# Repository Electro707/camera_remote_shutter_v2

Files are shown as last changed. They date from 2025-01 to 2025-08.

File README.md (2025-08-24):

# P1010 - Camera Remote Shutter Project V2
#### Rev 2

This is an open-source camera remote shutter.

This was the second revision of the [original project](https://github.com/Electro707/camera_remote_shutter), but is now treated as a seperate project due to scope creep.

Currently working on Rev 2, which is smaller and fixed some issues with V1

# Directory Structure
- `CAD`: FreeCAD enclosure and models
    - C1013: Bottom half of enclosure
    - C1014: Top half of enclosure
- `Firmware`: Firmware. Currently contains only test firmware
- `PCB`: KiCAD PCB Files
    - E1011: PCB
- `Release`: Locked in "released" files, such as Schematics, Gerbers, etc
- `SimTest`: A simulation I did in KiCAD for the trans-impedance amplifier

## Erratas
All hardware erratas and potential work-arounds are documented in [ERRATA.md](ERRATA.md)

## Firmware
WIP, currently only test firmware exists

### Setup
This project uses [stm32-cmake](https://github.com/ObKo/stm32-cmake) in the build process, so you must set it up and change the `CMAKE_TOOLCHAIN_FILE` variable in each firmware's CMAKE file. You must also download [STM32G0's MCU Package](https://github.com/STMicroelectronics/STM32CubeG0) and set the `STM32_CUBE_G0_PATH` variable to the download location.
Optionally if you have stm32cubeide installed, setup `STM32_TOOLCHAIN_PATH` in the CMAKE file, or remove it

### Compiling
To build any of the test or main applications, go into that directory and run the following:
```bash
mkdir -p build
cd build
cmake ../
make
```

### Programming
To upload the program, run the following stlink command
```bash
st-flash write <file_to_flash>.bin 0x08000000
```

Where the <file_to_flash> is the bin file inside of the build folder. `0x08000000` is the starting flash address for the STM32G0 family.

## KiCAD 3D Models
The 3D models for some components in the directory `PCB/3d_model/` are not included due to licensing reasons. You can grab the step files yourself and put it in that directory from the manufacturer. The models are
- CUI_DEVICES_SJ-2509N.step
- 615006138421_Download_STP_615006138421_rev1.stp
- c-1-1478035-0-b-3d.stp
- pec12r-4025f-n0024.stp

# License
This project is licensed under GPLv3. See [LICENSE.md](LICENSE.md) for details.

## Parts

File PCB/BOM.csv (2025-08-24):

Reference | Value | Footprint | Qty | DNP
BT2 | Battery | Connector_JST:JST_PH_B2B-PH-K_1x02_P2.00mm_Vertical | 1
C1 | 10pF | Capacitor_SMD:C_0805_2012Metric | 1
C2,C6,C14,C18 | 1pF | Capacitor_SMD:C_0805_2012Metric | 4
C3,C5,C11,C12,C17,C20 | 0.1uF | Capacitor_SMD:C_0805_2012Metric | 6
C4,C13 | 10uF | Capacitor_SMD:C_0805_2012Metric | 2
C7 | 1uF | Capacitor_SMD:C_0805_2012Metric | 1
C8 | 4.7uF | Capacitor_SMD:C_0805_2012Metric | 1
C9,C10,C19 | 10nF | Capacitor_SMD:C_0805_2012Metric | 3
D1 | D_Photo | LED_THT:LED_D5.0mm | 1
D4 | ESD5Zxx | Diode_SMD:D_SOD-523 | 1
F2 | Polyfuse | Fuse:Fuse_1210_3225Metric_Pad1.42x2.65mm_HandSolder | 1
FB1 | FerriteBead | Fuse:Fuse_0805_2012Metric | 1
H1,H2,H3,H4 | MountingHole_Pad | MountingHole:MountingHole_3.2mm_M3_DIN965_Pad | 4
J1 | External Trig | ProjectLibrary:MJ1-2503A | 1
J2 | Conn_01x02_Socket | Connector_PinHeader_2.54mm:PinHeader_1x02_P2.54mm_Vertical | 1
J4 | RJ12 | Connector_RJ:RJ25_Wayconn_MJEA-660X1_Horizontal | 1
J6 | Camera TRS | ProjectLibrary:MJ1-2503A | 1
J8 | USB_C_Receptacle_USB2.0_14P | Connector_USB:USB_C_Receptacle_GCT_USB4085 | 1
MK1 | Microphone | Sensor_Audio:POM-2244P-C3310-2-R | 1
Q3,Q4 | MMBF170 | Package_TO_SOT_SMD:SOT-23 | 2
R1,R21,R22 | 0 | Resistor_SMD:R_0805_2012Metric | 3
R2,R8 | 100k | Resistor_SMD:R_0805_2012Metric | 2
R5,R25,R27,R29,R30,R34,R36,R38,R39,R42,R45,R49,R50 | 1k | Resistor_SMD:R_0805_2012Metric | 13
R6,R7,R9,R14,R19,R28,R31,R32,R33,R35,R37,R41,R48 | 10k | Resistor_SMD:R_0805_2012Metric | 13
R10 | 200k | Resistor_SMD:R_0805_2012Metric | 1
R13 | 2.2k | Resistor_SMD:R_0805_2012Metric | 1
R16,R24,R53 | 0 | Resistor_SMD:R_0805_2012Metric | 3 | DNP
R17,R18 | 5.1k | Resistor_SMD:R_0805_2012Metric | 2
R23 | x | Resistor_SMD:R_0805_2012Metric | 1 | DNP
R26 | 1.3k | Resistor_SMD:R_0805_2012Metric | 1
R40 | 100 | Resistor_SMD:R_0805_2012Metric | 1
R43 | 10k | Resistor_SMD:R_0805_2012Metric | 1 | DNP
R51 | 500k | Resistor_SMD:R_0805_2012Metric | 1
R52 | 1M | Resistor_SMD:R_0805_2012Metric | 1
SW1,SW2,SW3 | SW_Push | Button_Switch_THT:SW_PUSH_6mm,Button_Switch_THT:SW_Tactile_SPST_Angled_PTS645Vx58-2LFS | 3
SW5 | RotaryEncoder_Switch | Rotary_Encoder:RotaryEncoder_Bourns_Vertical_PEC12R-3x17F-Sxxxx | 1
TP1,TP2,TP3,TP4 | TestPoint | TestPoint:TestPoint_Keystone_5005-5009_Compact,TestPoint:TestPoint_Pad_D1.5mm | 4
U1 | STM32G071K8Tx | Package_QFP:LQFP-32_7x7mm_P0.8mm | 1
U2,U8 | LTV-356T | Package_SO:SO-4_4.4x3.6mm_P2.54mm | 2
U3 | ER-TFTM1.28-1 | ProjectLibrary:1.28IN LCD | 1
U4 | BQ24072RGT | Package_DFN_QFN:VQFN-16-1EP_3x3mm_P0.5mm_EP1.6x1.6mm | 1
U5 | OPA2607 | Package_SO:SOIC-8_3.9x4.9mm_P1.27mm | 1
U6 | TS5A3357 | Package_SO:VSSOP-8_2.3x2mm_P0.5mm | 1
U9 | TLV75733PDBV | Package_TO_SOT_SMD:SOT-23-5 | 1

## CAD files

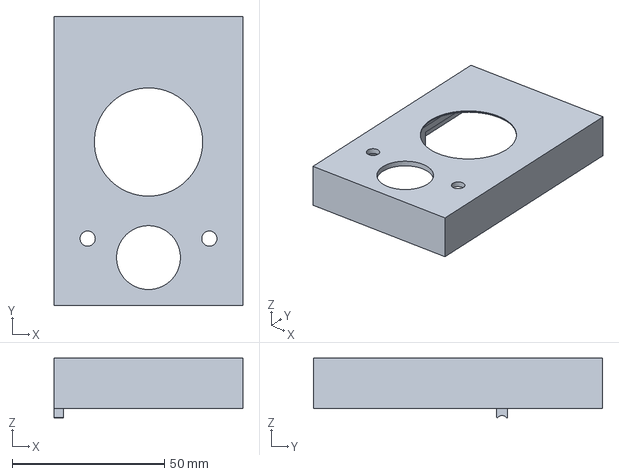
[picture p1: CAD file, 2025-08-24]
CAD/Enclosure.FCStd
62.0 x 95.0 x 19.7 mm

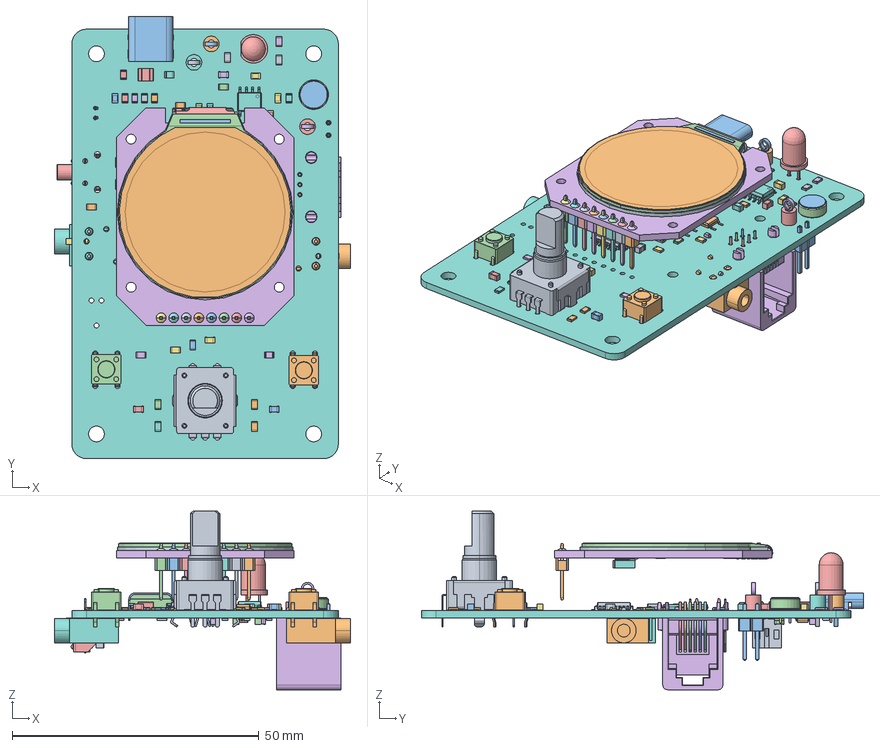
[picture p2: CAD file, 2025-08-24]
CAD/PCB_Rev2.FCStd
60.0 x 89.6 x 36.2 mm
SOT-23
R_0805_2012Metric
R_0805_2012Metric001
SW_PUSH_6mm
R_0805_2012Metric002
D_SOD-523
R_0805_2012Metric003
C_0805_2012Metric
LQFP-32_7x7mm_P0.8mm
R_0805_2012Metric004
C_0805_2012Metric001
R_0805_2012Metric005
LED_D5.0mm
R_0805_2012Metric006
C_0805_2012Metric002
R_0805_2012Metric007
ÃÂºÃÂ¿
ÃÂºÃÂ¿001
ÃÂºÃÂ¿002
ÃÂºÃÂ¿003
ÃÂºÃÂ¿004
ÃÂµÃ¨ÂÂ·ÃÂ°
Pin Header 8P
Pin Header 8P001
Pin Header 8P002
Pin Header 8P003
Pin Header 8P004
Pin Header 8P005
Pin Header 8P006
Pin Header 8P007
Pin Header 8P008
Pin Header 8P009
Pin Header 8P010
Pin Header 8P011
Pin Header 8P012
Pin Header 8P013
Pin Header 8P014
Pin Header 8P015
FPC-12
FPC-013
FPC-014
FPC-015
FPC-016
FPC-017
FPC-018
FPC-019
FPC-020
FPC-021
FPC-022
FPC-023
FPC-024
FPC-025
FPC-026
FPC-027
FPC-028
R_0805_2012Metric008
R_0805_2012Metric009
R_0805_2012Metric010
R_0805_2012Metric011
R_0805_2012Metric012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

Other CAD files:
CAD/Assembly.FCStd

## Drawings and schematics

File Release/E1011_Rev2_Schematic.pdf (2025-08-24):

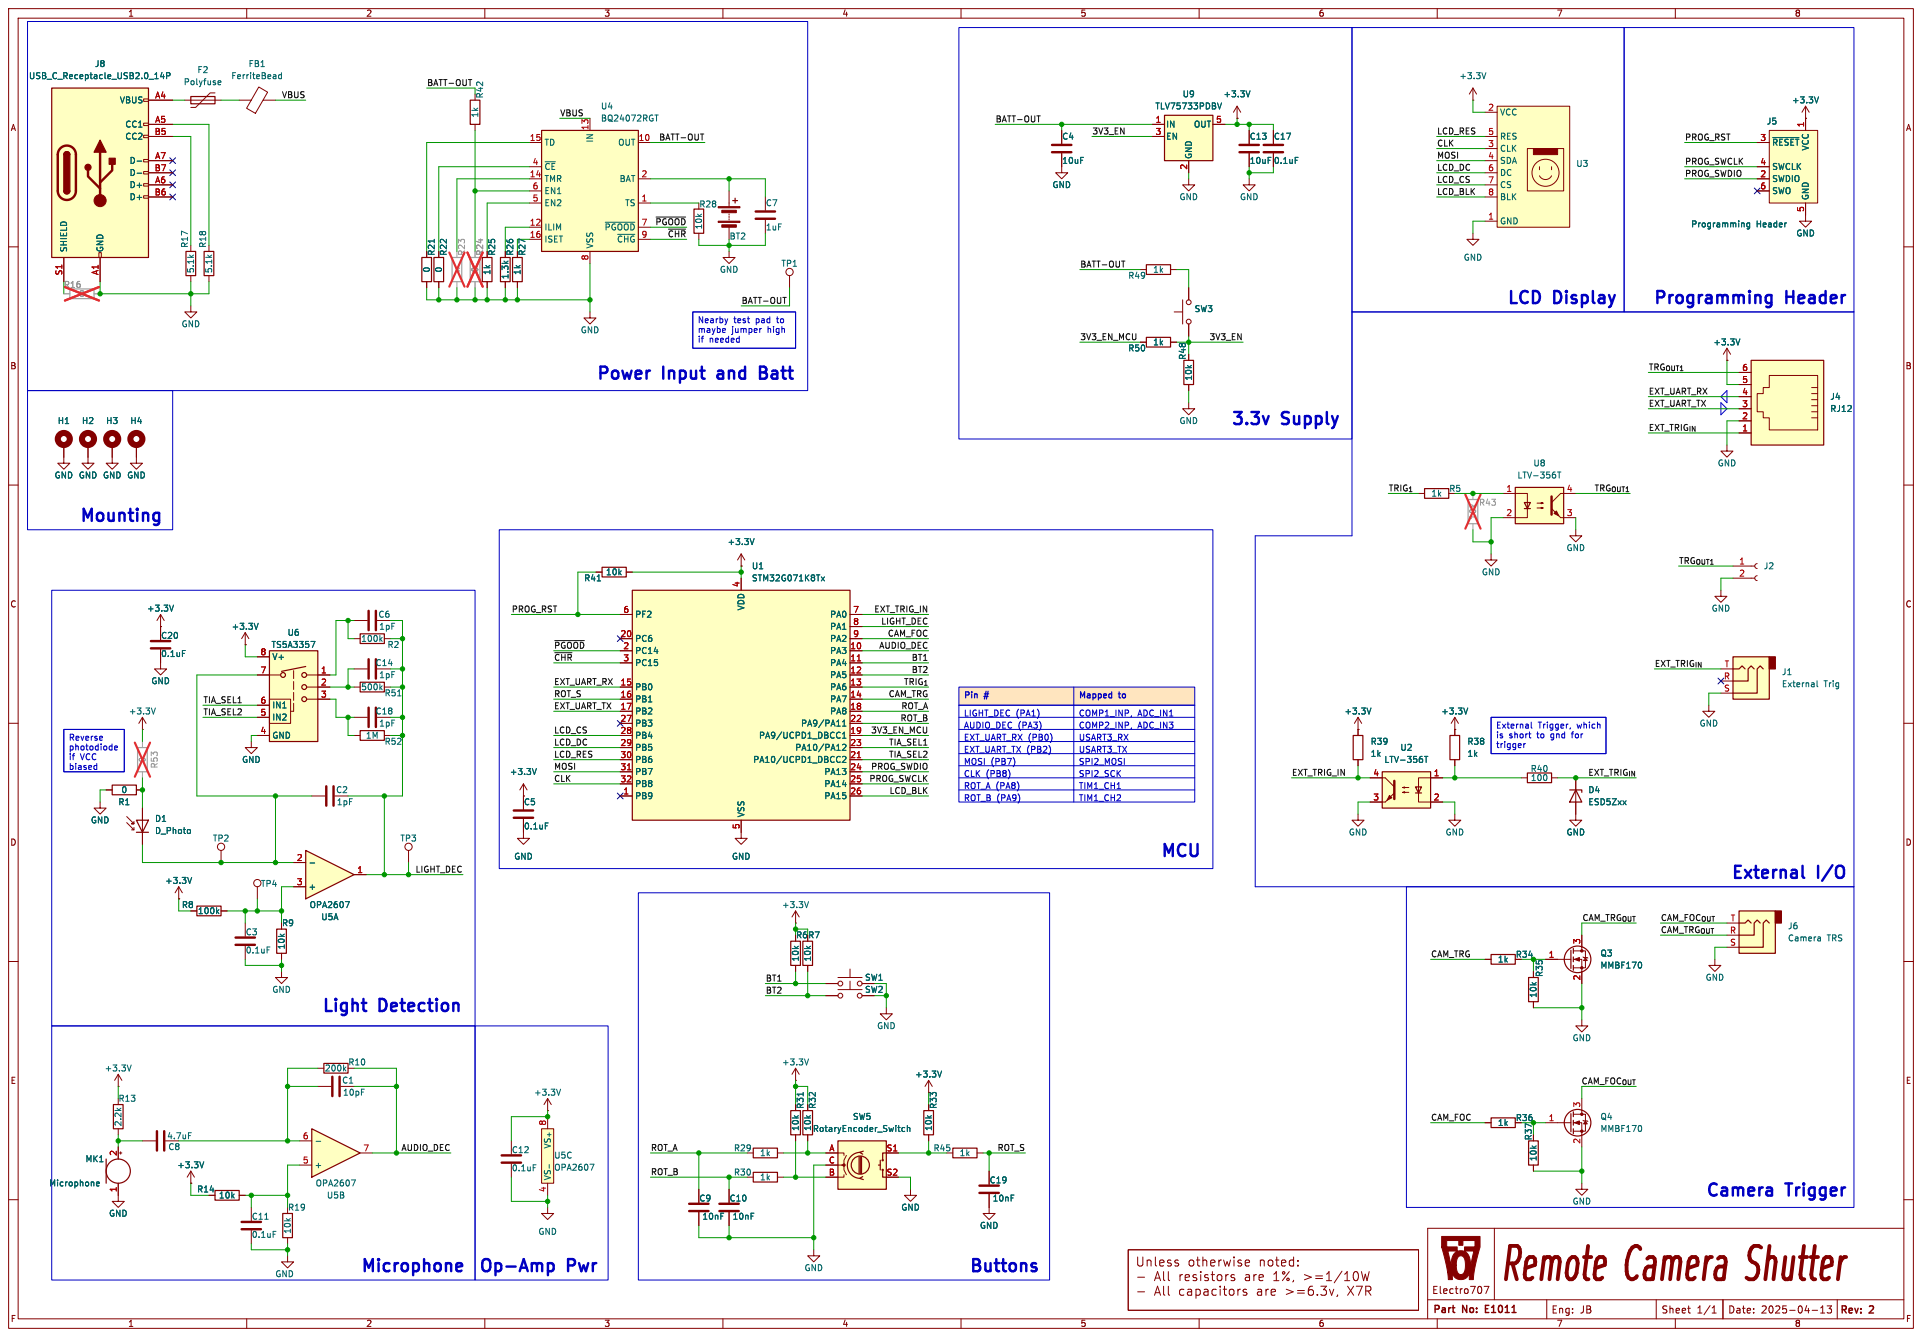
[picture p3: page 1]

8 OUT 10 BAT 2 TS 1 ~{PGOOD}7 ~{CHG}9 U4BQ24072RGT
VBUS

Nearby test pad to maybe jumper high

Power Input and Batt

External Trigger, which
is short to gnd for
trigger

Microphone Op-Amp Pwr

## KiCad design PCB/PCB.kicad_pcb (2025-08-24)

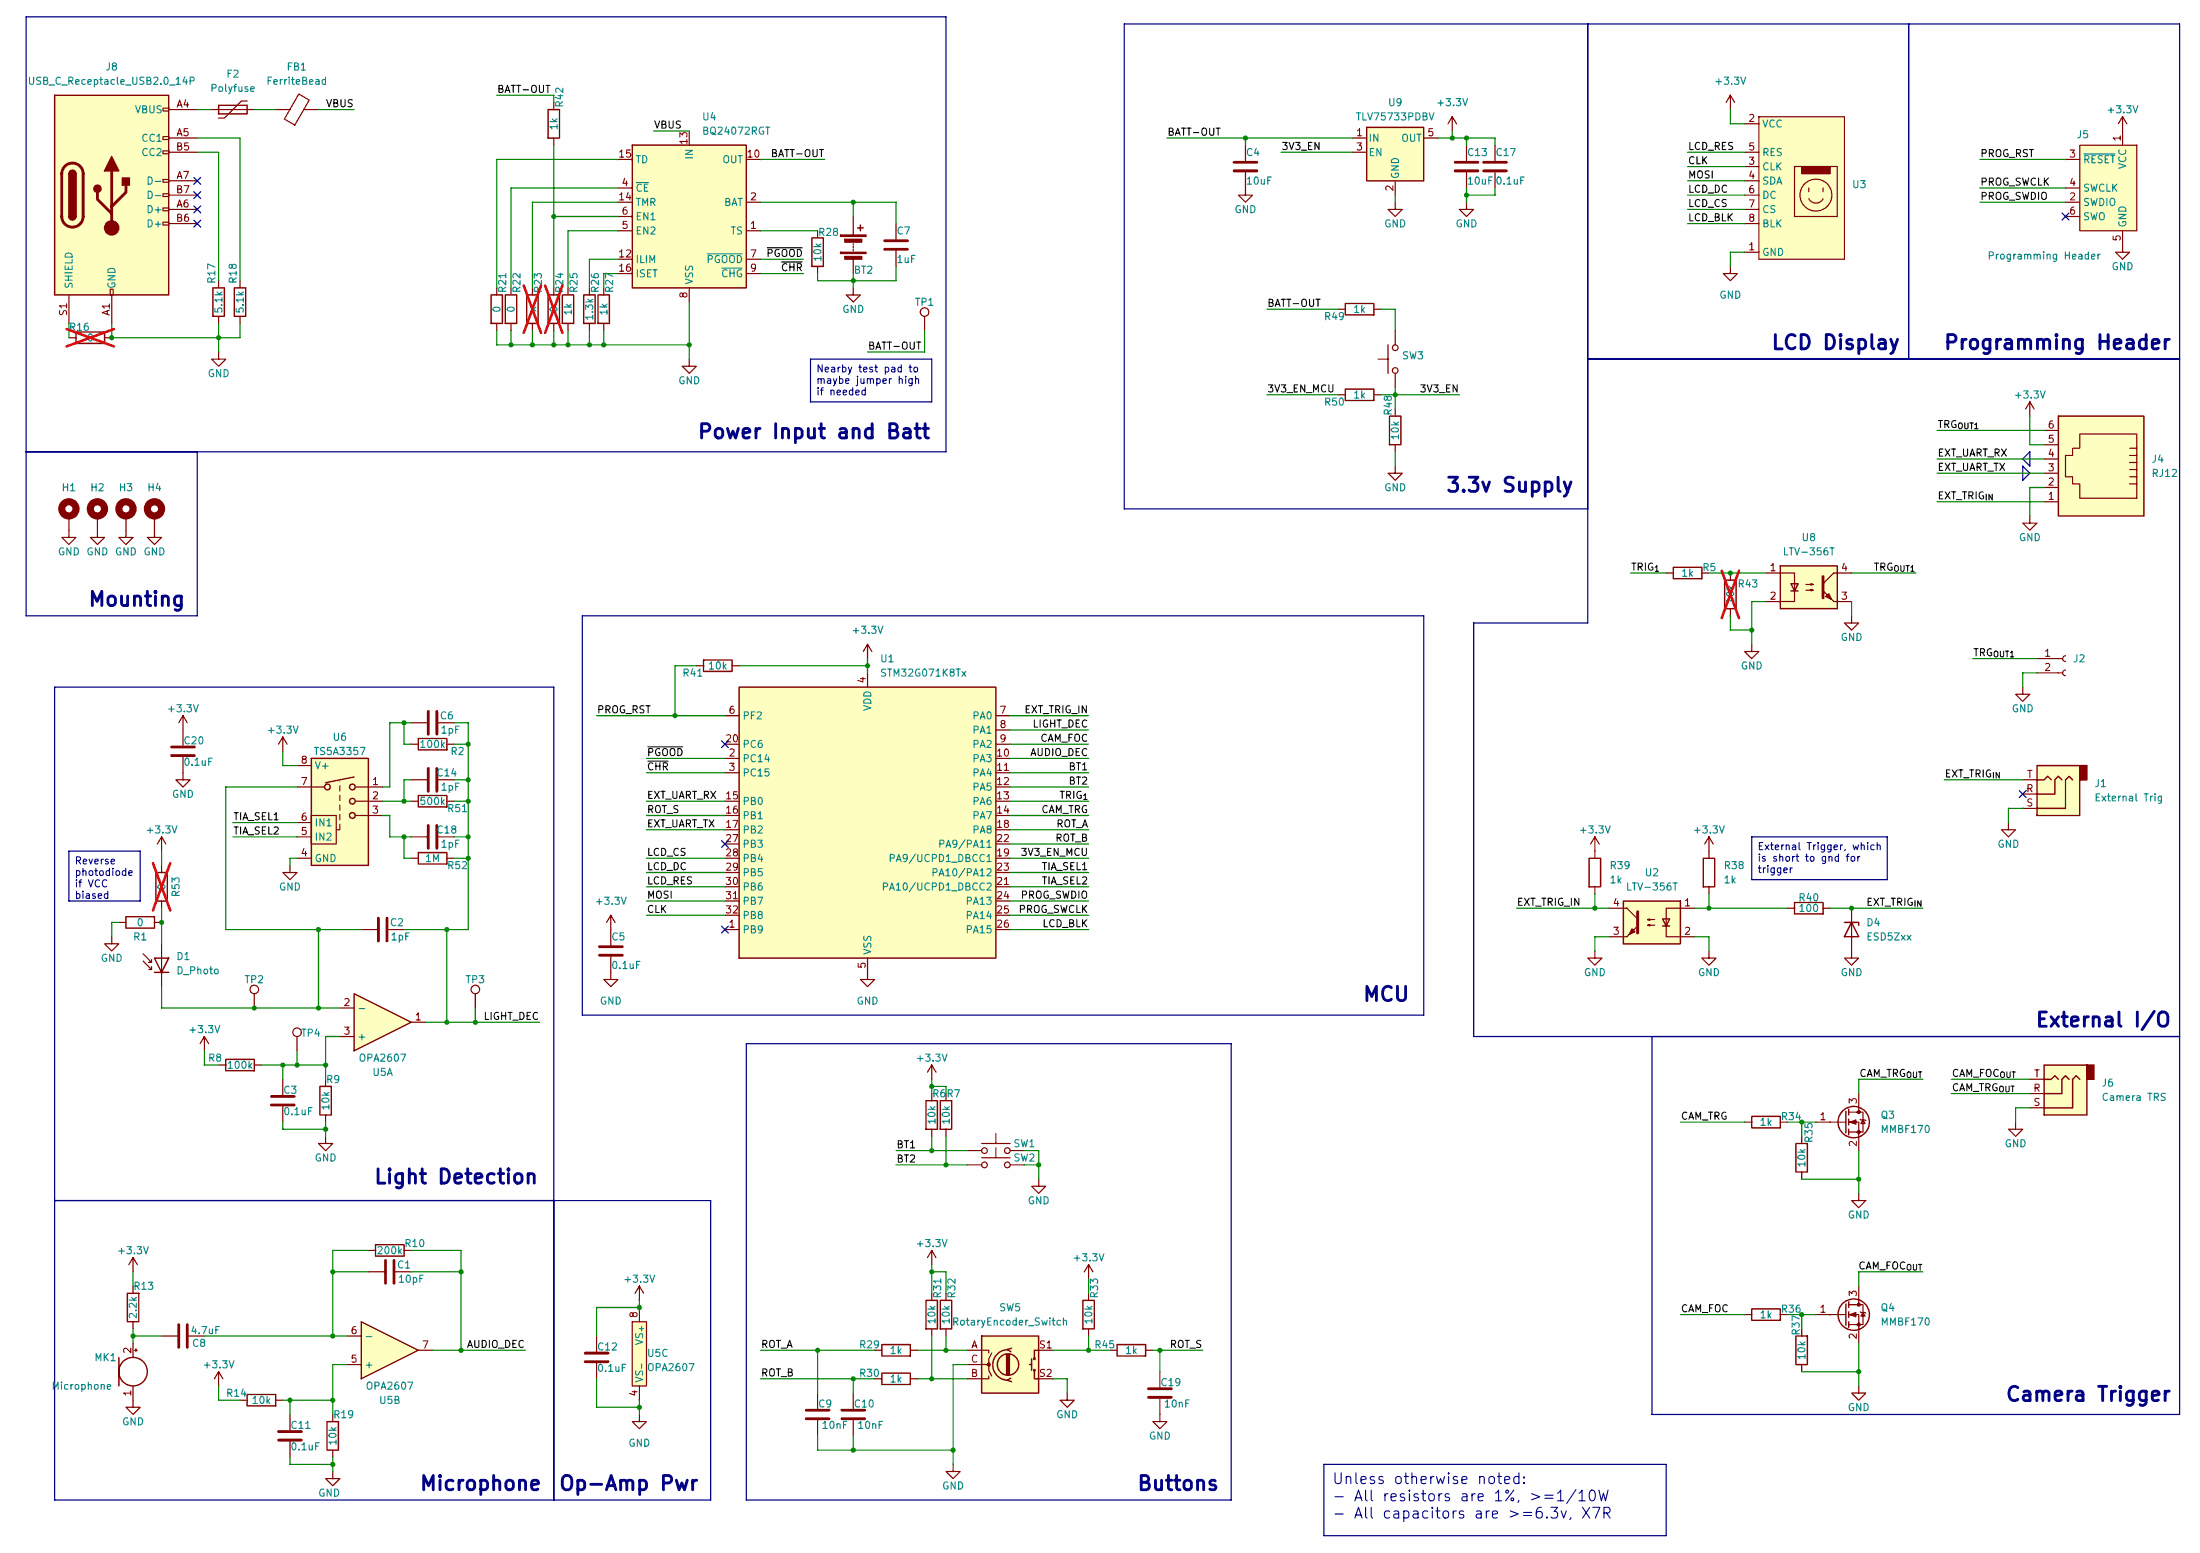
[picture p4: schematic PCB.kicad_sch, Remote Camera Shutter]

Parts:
BT2: Battery; JST_PH_B2B-PH-K_1x02_P2.00mm_Vertical
C1: 10pF; C_0805_2012Metric
C2, C6, C14, C18: 1pF; C_0805_2012Metric
C3, C5, C11, C12, C17, C20: 0.1uF; C_0805_2012Metric
C4, C13: 10uF; C_0805_2012Metric
C7: 1uF; C_0805_2012Metric
C8: 4.7uF; C_0805_2012Metric
C9, C10, C19: 10nF; C_0805_2012Metric
D1: D_Photo; LED_D5.0mm
D4: ESD5Zxx; D_SOD-523
F2: Polyfuse; Fuse_1210_3225Metric_Pad1.42x2.65mm_HandSolder
FB1: FerriteBead; Fuse_0805_2012Metric
H1, H2, H3, H4: MountingHole_Pad; MountingHole_3.2mm_M3_DIN965_Pad
J1: External Trig; MJ1-2503A
J2: Conn_01x02_Socket; PinHeader_1x02_P2.54mm_Vertical
J4: RJ12; RJ25_Wayconn_MJEA-660X1_Horizontal
J5: Programming Header; Tag-Connect_TC2030-IDC-NL_2x03_P1.27mm_Vertical
J6: Camera TRS; MJ1-2503A
J8: USB_C_Receptacle_USB2.0_14P; USB_C_Receptacle_GCT_USB4085
MK1: Microphone; POM-2244P-C3310-2-R
Q3, Q4: MMBF170; SOT-23
R1, R21, R22: 0; R_0805_2012Metric
R2, R8: 100k; R_0805_2012Metric
R5, R25, R27, R29, R30, R34, R36, R38, R39, R42, R45, R49, R50: 1k; R_0805_2012Metric
R6, R7, R9, R14, R19, R28, R31, R32, R33, R35, R37, R41, R48: 10k; R_0805_2012Metric
R10: 200k; R_0805_2012Metric
R13: 2.2k; R_0805_2012Metric
R16, R24, R53: 0; R_0805_2012Metric; not fitted
R17, R18: 5.1k; R_0805_2012Metric
R23: x; R_0805_2012Metric; not fitted
R26: 1.3k; R_0805_2012Metric
R40: 100; R_0805_2012Metric
R43: 10k; R_0805_2012Metric; not fitted
R51: 500k; R_0805_2012Metric
R52: 1M; R_0805_2012Metric
SW1, SW2: SW_Push; SW_PUSH_6mm
SW3: SW_Push; SW_Tactile_SPST_Angled_PTS645Vx58-2LFS
SW5: RotaryEncoder_Switch; RotaryEncoder_Bourns_Vertical_PEC12R-3x17F-Sxxxx
TP1: TestPoint; TestPoint_Pad_D1.5mm
TP2, TP3, TP4: TestPoint; TestPoint_Keystone_5005-5009_Compact
U1: STM32G071K8Tx; LQFP-32_7x7mm_P0.8mm
U2, U8: LTV-356T; SO-4_4.4x3.6mm_P2.54mm
U3: ER-TFTM1.28-1; 1.28IN LCD
U4: BQ24072RGT; VQFN-16-1EP_3x3mm_P0.5mm_EP1.6x1.6mm
U5: OPA2607; SOIC-8_3.9x4.9mm_P1.27mm
U6: TS5A3357; VSSOP-8_2.3x2mm_P0.5mm
U9: TLV75733PDBV; SOT-23-5

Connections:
+3.3V: C5.1, C12.2, C13.1, C17.1, C20.2, J4.5, J5.1 (VCC), R6.1, R7.1, R8.1, R13.2, R14.1, R31.1, R32.1, R33.1, R38.1, R39.1, R41.1, R53.2, U1.4 (VDD), U3.2 (VCC), U5.8 (VS_{+}), U6.8 (V+), U9.5 (OUT)
/3V3_EN: R48.1, R50.2, SW3.1, U9.3 (EN)
/3V3_EN_MCU: R50.1, U1.19 (PA9/UCPD1_DBCC1)
/AUDIO_DEC: C1.2, R10.1, U1.10 (PA3), U5.7
/BATT-OUT: C4.1, R42.1, R49.1, TP1.1, U4.10 (OUT), U4.11 (OUT), U9.1 (IN)
/BT1: R6.2, SW1.1, U1.11 (PA4)
/BT2: R7.2, SW2.1, U1.12 (PA5)
/CAM_FOC: R36.1, U1.9 (PA2)
/CAM_FOC_{OUT}: J6.T, Q4.3 (D)
/CAM_TRG: R34.1, U1.14 (PA7)
/CAM_TRG_{OUT}: J6.R, Q3.3 (D)
/CLK: U1.32 (PB8), U3.3 (CLK)
/EXT_TRIG_IN: R39.2, U1.7 (PA0), U2.4
/EXT_TRIG_{IN}: D4.1 (K), J1.T, J4.1, R40.2
/EXT_UART_RX: J4.4, U1.15 (PB0)
/EXT_UART_TX: J4.3, U1.17 (PB2)
/LCD_BLK: U1.26 (PA15), U3.8 (BLK)
/LCD_CS: U1.28 (PB4), U3.7 (CS)
/LCD_DC: U1.29 (PB5), U3.6 (DC)
/LCD_RES: U1.30 (PB6), U3.5 (RES)
/LIGHT_DEC: C2.2, C6.2, C14.2, C18.2, R2.2, R51.2, R52.2, TP3.1, U1.8 (PA1), U5.1
/MOSI: U1.31 (PB7), U3.4 (SDA)
/PROG_RST: J5.3 (~RESET), R41.2, U1.6 (PF2)
/PROG_SWCLK: J5.4 (SWCLK), U1.25 (PA14)
/PROG_SWDIO: J5.2 (SWDIO), U1.24 (PA13)
/ROT_A: C9.1, R29.1, U1.18 (PA8)
/ROT_B: C10.1, R30.1, U1.22 (PA9/PA11)
/ROT_S: C19.1, R45.2, U1.16 (PB1)
/TIA_SEL1: U1.23 (PA10/PA12), U6.6 (IN1)
/TIA_SEL2: U1.21 (PA10/UCPD1_DBCC2), U6.5 (IN2)
/TRG_{OUT}_{1}: J2.1, J4.6, U8.4
/TRIG_{1}: R5.1, U1.13 (PA6)
/VBUS: FB1.2, U4.13 (IN)
/~CHR: U1.3 (PC15), U4.9 (~CHG)
/~PGOOD: U1.2 (PC14), U4.7 (~PGOOD)
GND: BT2.2 (-), C3.1, C4.2, C5.2, C7.2, C9.2, C10.2, C11.1, C12.1, C13.2, C17.2, C19.2, C20.1, D4.2 (A), H1.1, H2.1, H3.1, H4.1, J1.S, J2.2, J4.2, J5.5 (GND), J6.S, J8.A1 (GND), J8.A12 (GND), J8.B1 (GND), J8.B12 (GND), MK1.1 (-), Q3.2 (S), Q4.2 (S), R1.1, R9.1, R16.2, R17.2, R18.2, R19.1, R21.2, R22.2, R23.2, R24.2, R25.2, R26.2, R27.2, R28.2, R35.1, R37.1, R43.2, R48.2, SW1.2, SW2.2, SW5.C, SW5.S2, U1.5 (VSS), U2.2, U2.3, U3.1 (GND), U4.8 (VSS), U4.17 (VSS), U5.4 (VS_{-}), U6.4 (GND), U8.2, U8.3, U9.2 (GND)
unnamed: BT2.1 (+), C7.1, U4.2 (BAT), U4.3 (BAT)
unnamed: C6.1, R2.1, U6.1
unnamed: C14.1, R51.1, U6.2
unnamed: C18.1, R52.1, U6.3
unnamed: D1.2 (A), R1.2, R53.1
unnamed: C2.1, D1.1 (K), TP2.1, U5.2 (-), U6.7
unnamed: F2.1, J8.A4 (VBUS), J8.A9 (VBUS), J8.B4 (VBUS), J8.B9 (VBUS)
unnamed: F2.2, FB1.1
unnamed: J8.A5 (CC1), R18.1
unnamed: J8.B5 (CC2), R17.1
unnamed: J8.S1 (SHIELD), R16.1
unnamed: C8.1, MK1.2 (+), R13.1
unnamed: Q3.1 (G), R34.2, R35.2
unnamed: Q4.1 (G), R36.2, R37.2
unnamed: R29.2, R32.2, SW5.A
unnamed: R30.2, R31.2, SW5.B
unnamed: R33.2, R45.1, SW5.S1
unnamed: R38.2, R40.1, U2.1
unnamed: R5.2, R43.1, U8.1
unnamed: R49.2, SW3.2
unnamed: R24.1, R42.2, U4.6 (EN1)
unnamed: R25.1, U4.5 (EN2)
unnamed: R26.1, U4.12 (ILIM)
unnamed: R27.1, U4.16 (ISET)
unnamed: R21.1, U4.15 (TD)
unnamed: R23.1, U4.14 (TMR)
unnamed: R28.1, U4.1 (TS)
unnamed: R22.1, U4.4 (~CE)
unnamed: C3.2, R8.2, R9.2, TP4.1, U5.3 (+)
unnamed: C11.2, R14.2, R19.2, U5.5 (+)
unnamed: C1.1, C8.2, R10.2, U5.6 (-)

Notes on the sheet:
External I/O
3.3v Supply
Camera Trigger
Light Detection
Op-Amp Pwr
Power Input and Batt
MCU
Microphone
Mounting
Programming Header
Buttons
LCD Display
Nearby test pad to maybe jumper high if needed
Reverse photodiode if VCC biased
External Trigger, which is short to gnd for trigger
Unless otherwise noted: - All resistors are 1%, >=1/10W - All capacitors are >=6.3v, X7R

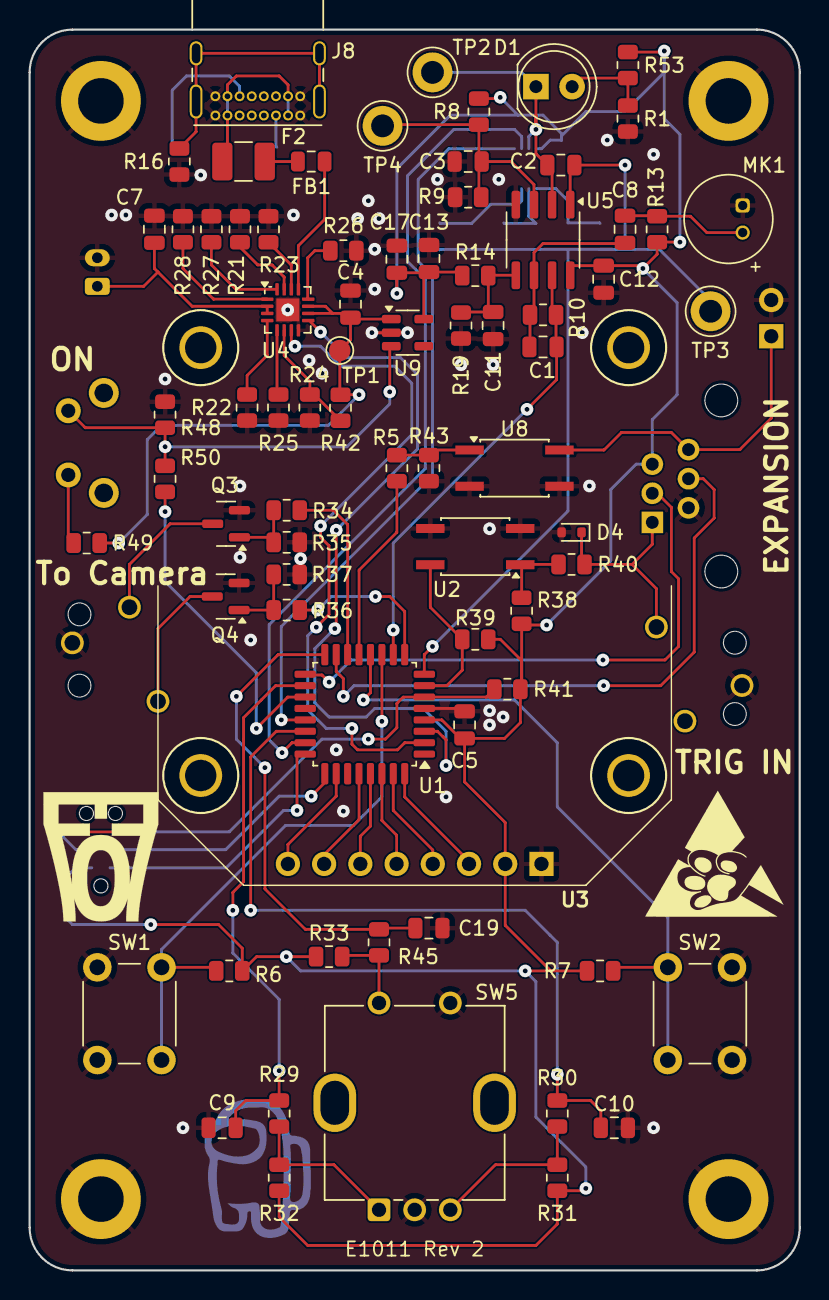
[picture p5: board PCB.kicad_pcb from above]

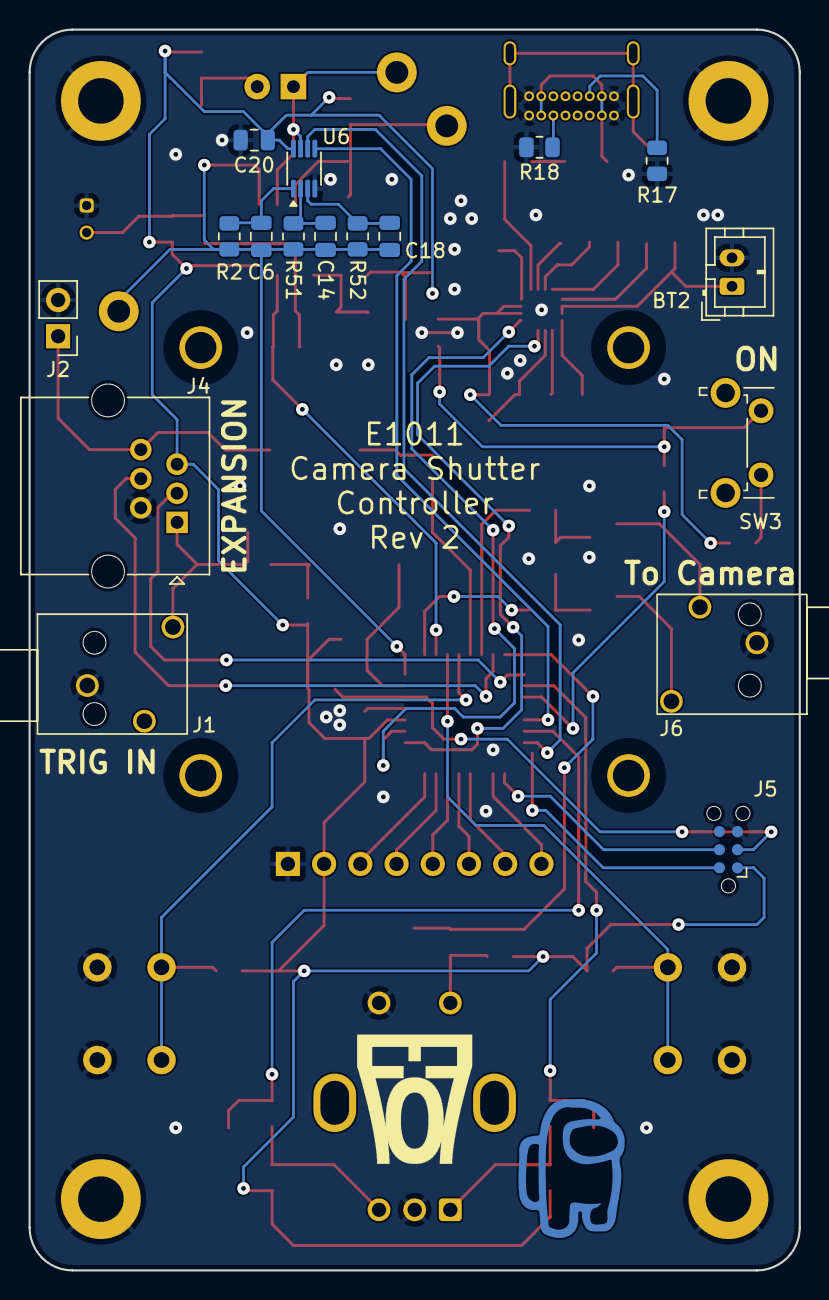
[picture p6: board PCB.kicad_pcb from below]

Board: 2 copper layers, 54.0 x 87.0 mm, 96 parts (17 on the bottom side), 67 nets.

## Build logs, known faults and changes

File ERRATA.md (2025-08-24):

# Purpose
This document describes the hardware erratas and any potential fix using said hardware.

# E1011 Rev 2: Driver Board
## Errata 2: PA11 and PA9 Flipping
Due to how the schematic showcased pins PA9 and PA11, I assumed what I was connecting `ROT_B` to was PA9, while in reality it was PA11 unless the pin is remapped in software, which leads the original PA11 to not be usable, which had `3V3_EN_MCU` connected to it

### Fix
Flip PA9 and PA11 connections as follows:
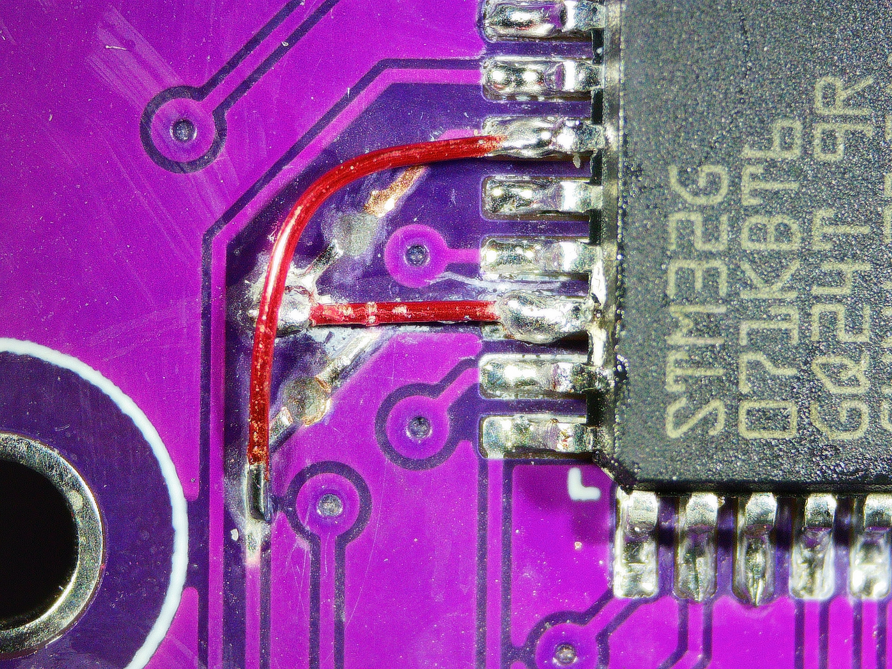
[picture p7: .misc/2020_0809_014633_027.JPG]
Bodge Wire


# E1011 Rev 1: Driver Board

## Errata 1: Crystal Enable
The inverting and non-inverting inputs of the op-amp were fixed

### Fix
None other than time-consuming bodge wiring

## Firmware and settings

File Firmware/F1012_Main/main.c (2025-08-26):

#include "stm32g0xx.h"
#include "stm32g0xx_ll_rcc.h"
#include "stm32g0xx_ll_system.h"
#include "stm32g0xx_ll_utils.h"
#include "gc9a01.h"
#include "config.h"
#include <stddef.h>
#include <stdlib.h>
#include <string.h>
#include "nanoprintf.h"

void autoShutdownService(void);
void shutdownDevice(void);
void selectTiaSens(uint8_t sens);
void line_draw_abstract(uint8_t *canvasBuff, uint16_t canvasW, uint16_t x0, uint16_t y0, uint16_t x1, uint16_t y1);
void line_draw_vert_abstract(uint8_t *canvasBuff, uint16_t canvasW, uint16_t x, uint16_t h);

// run-time modes
typedef enum{
	STATE_RESET,		// reset state
	STATE_STANDBY,		// standby, not doing anything with pictures
	STATE_EDITING_VAR,	// editing variable in UI
	STATE_ARMED,		// armed, waiting to take picture
	STATE_TRIG,			// camera triggered
	STATE_SHUTDOWN		// shutdown
}stateMachine_e;

// to keep track of what we are editing through UI
typedef enum{
	UI_EDIT_SHUTTER_TIME,
	UI_EDIT_TRIG_TIME,
	UI_EDIT_TIMELAPSE_N,
	UI_EDIT_TIMELAPSE_DUR,
}uiEditMode_e;

stateMachine_e state;
uint autoShutdownTimer;		// counter for auto shutting down
uint lastEncoderState;
uint lastLcdUpdate;			// last time since we updated the lcd
bool trigUpdateLcd;

void initMcu(void){
	// init clock, 32Mhz system and periferal clock
	LL_FLASH_SetLatency(LL_FLASH_LATENCY_1);
	while(LL_FLASH_GetLatency() != LL_FLASH_LATENCY_1);

	LL_RCC_HSI_Enable();
	while(LL_RCC_HSI_IsReady() != 1);

	LL_RCC_PLL_ConfigDomain_SYS(LL_RCC_PLLSOURCE_HSI, LL_RCC_PLLM_DIV_1, 8, LL_RCC_PLLR_DIV_2);
	LL_RCC_PLL_Enable();
	LL_RCC_PLL_EnableDomain_SYS();
	while(LL_RCC_PLL_IsReady() != 1);

	LL_RCC_SetAHBPrescaler(LL_RCC_SYSCLK_DIV_1);
	LL_RCC_SetSysClkSource(LL_RCC_SYS_CLKSOURCE_PLL);
	while(LL_RCC_GetSysClkSource() != LL_RCC_SYS_CLKSOURCE_STATUS_PLL);

	LL_RCC_SetAPB1Prescaler(LL_RCC_APB1_DIV_1);
	LL_Init1msTick(64000000);
	LL_SetSystemCoreClock(64000000);

	// remap PA11 to PA9
	RCC->APBENR2 |= RCC_APBENR2_SYSCFGEN;
	SYSCFG->CFGR1 |= SYSCFG_CFGR1_UCPD2_STROBE | SYSCFG_CFGR1_UCPD1_STROBE;
	// SYSCFG->CFGR1 |= SYSCFG_CFGR1_PA11_RMP;

	// init gpio
	// enable clock for port a, b, and c
	RCC->IOPENR |= RCC_IOPENR_GPIOAEN | RCC_IOPENR_GPIOBEN | RCC_IOPENR_GPIOCEN;

	// PA6 (Trig_1) - output
	// PA7 (CAM_TRIG) - output
	// PA8 (ROT_A) - alternate
	// PA9 (ROT_B, fixed through pcb mod) - alternate
	// PA10 (TIA_SEL2) - output
	// PA11 (3V3_EN_MCU, fixed through pcb mod) - output
	// PA12 (TIA_SEL1) - output
	// PA13 (SWDIO) - alternate
	// PA14 (SWCLK) - alternate
	// PA15 (LCB_BLK) - output
	GPIOA->MODER = 0x695a5fff;
	GPIOA->AFR[1] |= 0x22;              // A8 and A9 -> AF2 (Timer 1 inputs)

	// port b output
	// PB4 (LCD_CS) -> output
	// PB5 (LCD_DC) -> output
	// PB6 (LCD_RES) -> output
	// PB7 (MOSI) -> alternate function
	// PB8 (MISO) -> alternate function
	GPIOB->MODER = 0xFFFE95FF;
	GPIOB->OSPEEDR = 0x0003EA00;        // all high speed for B4 to B6, very high speed for B7-B8
	GPIOB->AFR[0] |= 0x01 << 28;        // B7 -> AF1
	GPIOB->AFR[1] |= 0x01 << 0;         // B8 -> AF1

	// bring all output to reset state
	GPIOA->ODR = 0x800; // pa11
	GPIOB->ODR = 0;
	GPIOC->ODR = 0;

	// init spi, clk/2 (32Mhz), master
	RCC->APBENR1 |= RCC_APBENR1_SPI2EN;
	SPI2->CR2 = 0x0700;
	SPI2->CR1 = 0x0304;

	// init adc
	RCC->APBENR2 |= RCC_APBENR2_ADCEN;
	// Disable ADC in case it was beforehand
	if(ADC1->CR & ADC_CR_ADEN){
		ADC1->CR |= ADC_CR_ADDIS;
		while(ADC1->CR & ADC_CR_ADDIS);
	}

	ADC1->CFGR2 = 0x40000000;       // PCLK/2
	ADC1->SMPR = (0b11 << ADC_SMPR_SMP1_Pos);   // 12.5 ADC clock cycles for sampling time
	ADC1->CHSELR = 1 << 1;          // light as input
	// ADC1->CHSELR = 1 << 3;          // mic as input
	ADC1->CR = ADC_CR_ADVREGEN;      // ADVREGEN=1

	// init timer 1 in quatrature input mode (pa8-ch1 and pa9-ch2)
	RCC->APBENR2 |= RCC_APBENR2_TIM1EN;
	TIM1->SMCR = 0x0003;        // encoder mode 3 (up and down)
	TIM1->CCER = 0x22;      // falling edge
	TIM1->CCMR1 = (0b0110 << TIM_CCMR1_IC1F_Pos) | (0b0110 << TIM_CCMR1_IC1F_Pos) | TIM_CCMR1_CC1S_1 | TIM_CCMR1_CC2S_1;
	TIM1->CR2 = 0x0;
	TIM1->CR1 = 0x1;

	// init timer 14 as the real time interrupt of 1mS
	RCC->APBENR2 |= RCC_APBENR2_TIM14EN;
	TIM14->PSC = 512;
	TIM14->ARR = 125;
	TIM14->CNT = 0;
	TIM14->CR1 = TIM_CR1_URS;
	TIM14->DIER = TIM_DIER_UIE;

	// init timer 6 as a longer timer, period of 10 seconds
	RCC->APBENR1 |= RCC_APBENR1_TIM6EN;
	TIM6->CR1 = TIM_CR1_URS;
	TIM6->DIER = TIM_DIER_UIE;
	TIM6->PSC = 40000;
	TIM6->ARR = 16000;
	TIM6->CNT = 0;

	// set led backlight on
	GPIOA->ODR |= 1 << 15;
	DISP_CS_1;

	NVIC_EnableIRQ(TIM6_DAC_LPTIM1_IRQn);
	NVIC_EnableIRQ(TIM14_IRQn);

	SPI2->CR1 |= SPI_CR1_SPE;
}

void adcCal(void){
	unsigned int cal = 0;
	uint8_t n = 8;
	while(n--){
		ADC1->CR |= ADC_CR_ADCAL;
		while(ADC1->CR & ADC_CR_ADCAL);
		cal += ADC1->CALFACT + 1;
	}
	cal >>= 3;
	ADC1->CALFACT = cal;
}

void initSetupScreen(void){
	uint y = 50;
	gc9a01_fill_screen(gc9a01_color_black);

	gc9a01_print_text_sma("Shutter Time:", 50, y, gc9a01_color_black, gc9a01_color_white, ALIGN_LEFT, NULL);
	y += 16;
	
	gc9a01_print_text_sma("Time To Trig:", 50, y, gc9a01_color_white, gc9a01_color_black, ALIGN_LEFT, NULL);
	y += 16;

	gc9a01_print_text_sma("Timelapse: ", 50, y, gc9a01_color_white, gc9a01_color_black, ALIGN_LEFT, NULL);
	y += 16;

	gc9a01_print_text_sma("N Pics: ", 50, y, gc9a01_color_white, gc9a01_color_black, ALIGN_LEFT, NULL);
	y += 16;

	gc9a01_print_text_sma("Interval: ", 50, y, gc9a01_color_white, gc9a01_color_black, ALIGN_LEFT, NULL);
	y += 16;
}

int main(void)
{
	char nStr[10];

	initMcu();
	autoShutdownTimer = 0;
	lastLcdUpdate = 1000;		// technically infinite
	trigUpdateLcd = false;

	selectTiaSens(0);


	gc9a01_init();


	initSetupScreen();

	TIM1->CNT = 100;
	lastEncoderState = 100;

	TIM14->CR1 |= TIM_CR1_CEN;		// enable timer
	TIM6->CR1 |= TIM_CR1_CEN;		// enable timer
	__enable_irq();

	for(EVER){
		// todo: trigger if encoder is rotated or button pressed to reset auto shutdown timer
		if(trigUpdateLcd){
			if(lastEncoderState != TIM1->CNT){
				lastEncoderState = TIM1->CNT;
				npf_snprintf(nStr, 5, "%04u", (uint)TIM1->CNT);
        		gc9a01_print_text_sma(nStr, 162, 50, 0xFFFF, 0, ALIGN_LEFT, NULL);
				trigUpdateLcd = true;
			}
		}
	}
	return 0;
}

/*
 * real time interrupt triggered by TIMx
 * this runs every 1Khz
 */
void TIM14_IRQHandler(void){
	TIM14->SR = 0;		// clear pending interrupt

	if(trigUpdateLcd == false){
		if(lastLcdUpdate >= 100){
			trigUpdateLcd = true;
		}else{
			lastLcdUpdate++;
		}
	}
}

// called once every 10 seconds
void TIM6_DAC_LPTIM1_IRQHandler(void){
	TIM6->SR = 0;	// clear pending interrupt
	
	autoShutdownTimer += 1;
	if(autoShutdownTimer > AUTO_SHUTDOWN_INTERVAL){
		shutdownDevice();
	}
}

// service to clear the auto-shutdown timer
void autoShutdownService(void){
	autoShutdownTimer = 0;
}

void shutdownDevice(void){
	GPIOA->BRR = 1 << PIN_PSU_ENABLE;
}

/**
 * Selects the amplification amount from the TransImpedance Amplifier circuit
 * Range 0 (disabled) to 3 (max amp)
 */
void selectTiaSens(uint8_t sens){
	switch(sens){
		case 0:
			GPIOA->BRR = (1 << PIN_TIA_SEL_1);          // clear
			GPIOA->BRR = (1 << PIN_TIA_SEL_2);          // clear
			break;
		case 1:
			GPIOA->BSRR = (1 << PIN_TIA_SEL_1);         // set
			GPIOA->BSRR = (1 << PIN_TIA_SEL_2*2);       // clear
			break;
		case 2:
			GPIOA->BSRR = (1 << PIN_TIA_SEL_1*2);       // clear
			GPIOA->BSRR = (1 << PIN_TIA_SEL_2);         // set
			break;
		case 3:
			GPIOA->BSRR = (1 << PIN_TIA_SEL_1);         // set
			GPIOA->BSRR = (1 << PIN_TIA_SEL_2);         // set
			break;
		default:
			// todo: error handling
			break;
	}
}

void line_draw_vert_abstract(uint8_t *canvasBuff, uint16_t canvasW, uint16_t x, uint16_t h){
	int16_t canvasIdx;

	for(int y=0;y<h;y++){
		canvasIdx = (y*canvasW) + x / 8;
		canvasBuff[canvasIdx] |= 1 << (x & 0b111);
	}
}

/**
 * draws a canvas
 * buffer is [Y][X/8], and is bit filled
 */
void line_draw_abstract(uint8_t *canvasBuff, uint16_t canvasW, uint16_t x0, uint16_t y0, uint16_t x1, uint16_t y1){
	// https://en.wikipedia.org/wiki/Bresenham's_line_algorithm#All_cases
	int16_t dx = abs(x1-x0);
	int16_t dy = -abs(y1-y0);
	int16_t sx = x0 < x1 ? 1 : -1;
	int16_t sy = y0 < y1 ? 1 : -1;
	int16_t error = dx + dy;

	int16_t canvasIdx;

    while(1){
        canvasIdx = (y0*canvasW) + x0 / 8;
        if(canvasIdx < 0){
            canvasIdx = 0;
        }
        canvasBuff[canvasIdx] |= 1 << (x0 & 0b111);

		if((2*error) >= dy){
			if(x0 == x1){break;}
			error += dy;
			x0 += sx;
		}
		if((2*error) <= dx){
			if(y0 == y1){break;}
			error += dx;
			y0 += sy;
		}

	}
}

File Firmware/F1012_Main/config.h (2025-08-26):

#ifndef CONFIG_H
#define CONFIG_H

#include "stm32g0xx_ll_gpio.h"
#include <sys/_types.h>

#define EVER    ;;

#define PIN_TIA_SEL_1		12      // pa12
#define PIN_TIA_SEL_2		10      // pa10

#define PIN_PSU_ENABLE		11


#define DISP_CS_GPIO_Port   GPIOB
#define DISP_CS_Pin         LL_GPIO_PIN_4

#define DISP_DC_GPIO_Port   GPIOB
#define DISP_DC_Pin         LL_GPIO_PIN_5

#define DISP_RES_GPIO_Port  GPIOB
#define DISP_RES_Pin        LL_GPIO_PIN_6

// how many 10 second increments before we auto-shutdown
// #define AUTO_SHUTDOWN_INTERVAL		3		// 30 seconds
#define AUTO_SHUTDOWN_INTERVAL		60		// 600 seconds

#define NANOPRINTF_IMPLEMENTATION

#define true 1
#define false 0

typedef unsigned int bool;
typedef unsigned int uint;

#endif

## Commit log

2025-01-19 Initial commit, files push
    [Assembly.FCStd, BOM.csv, MainBody.FCStd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]
2025-08-24 Rev 2 of the PCB with modified test firmware and enclosure
    [Assembly.FCStd, BOM.csv, Enclosure.FCStd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]
2025-08-24 Finished first rev of top enclosure
    [Assembly.FCStd, Enclosure.FCStd, PCB_Rev2.FCStd]
